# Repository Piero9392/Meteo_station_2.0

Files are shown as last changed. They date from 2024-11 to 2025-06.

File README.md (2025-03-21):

# LoRa-Based Wireless Weather Station 📡📶

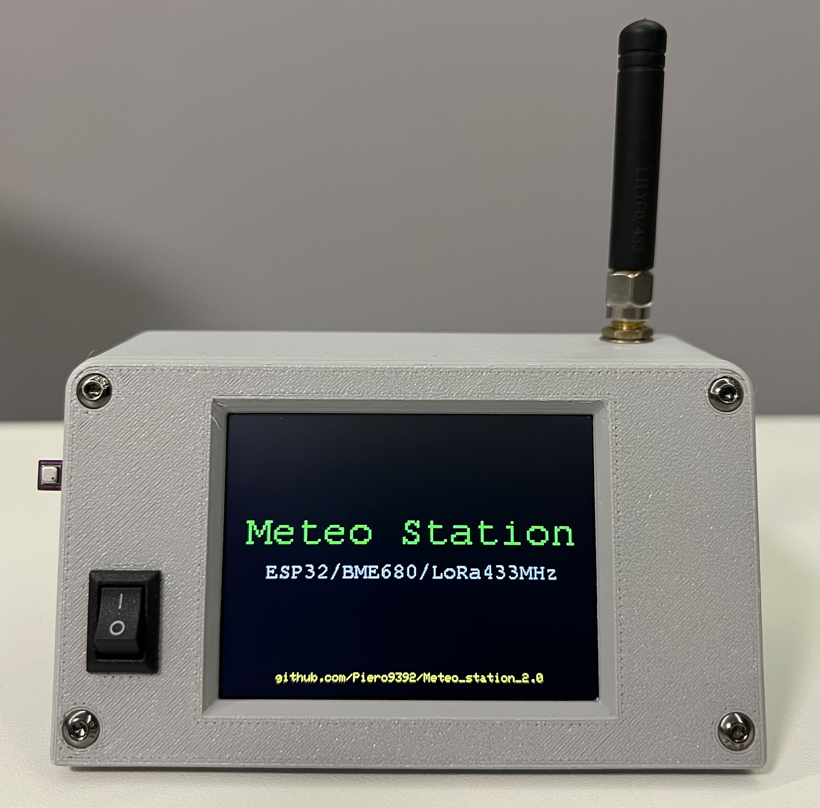
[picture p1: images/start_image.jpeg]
 
 
## Project Overview

This LoRa-based wireless weather station monitors a wide range of environmental parameters, including:
* Temperature 🌡️
* Humidity ☔️
* Pressure ⏱️
* Dew Point 💧
* Gas resistance
* Indoor Air Quality (IAQ) index 💭
* CO₂ 💨
* Volatile Organic Compounds (VOCs) 🗯️
* Altitude ⛰️

The station consists of two LoRa-equipped devices, a Sender and a Receiver, both utilizing the BME680 sensor. The Sender measures environmental parameters and transmits the data over LoRa to the Receiver, which can be positioned several kilometers away. This setup is suitable for applications like monitoring indoor and outdoor environments around your home.

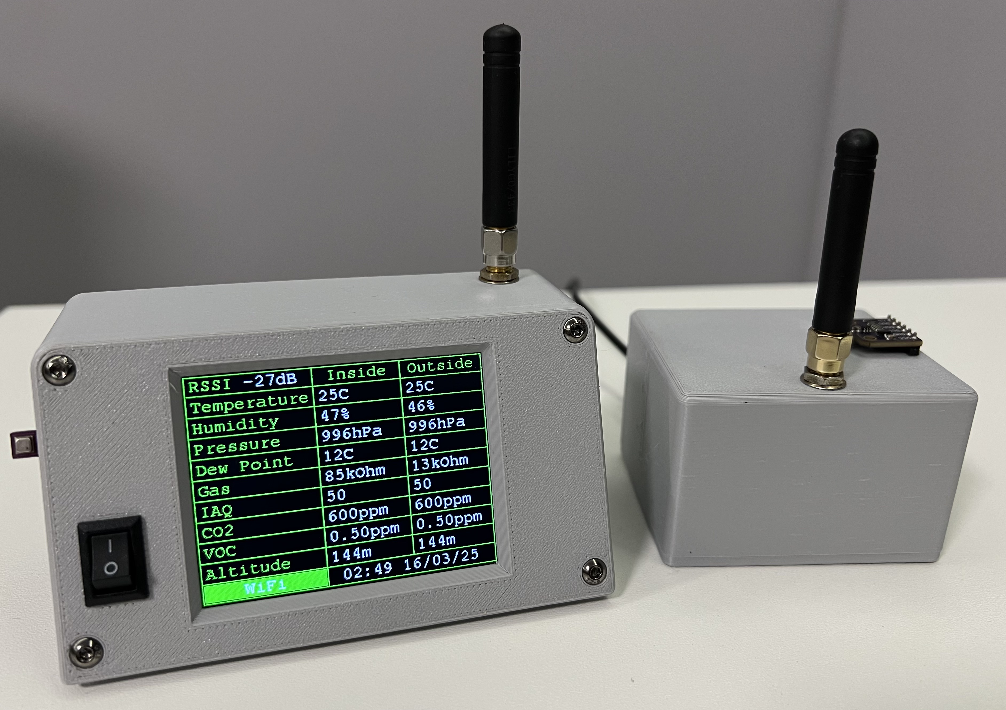
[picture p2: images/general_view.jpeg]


## Data Display and Monitoring

The Receiver provides multiple options for data visualization:
* Onboard Display: View data in real-time on the Receiver’s 2.4-inch TFT screen 🖥️.
* Cloud Integration: Send data via Wi-Fi to Blynk.Cloud or ThingSpeak.com for remote monitoring. You can access real-time and historical data using the Blynk IoT or ThingView applications on iOS/Android or via a web browser 📱🌐.

Additionally, it retrieves the current Time 🕖 and Date 📅 from the NTP server at NTP Pool.

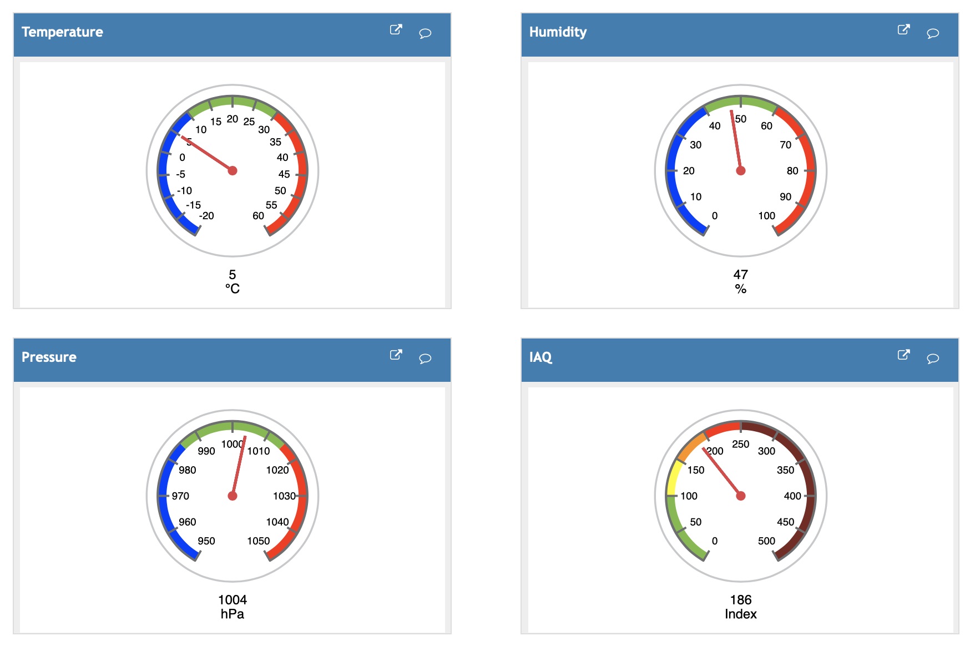
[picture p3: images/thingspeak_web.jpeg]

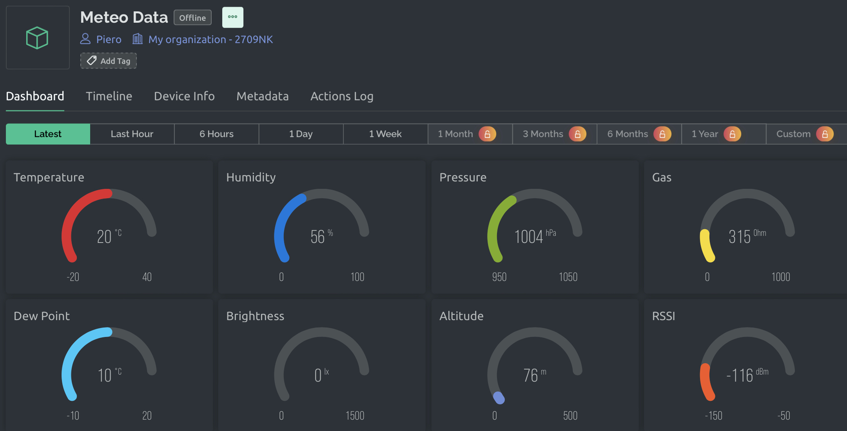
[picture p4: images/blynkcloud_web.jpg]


## Hardware Components

* Sender 📡:
  * 🛠Microcontroller: ESP32 WROOM DA (30 Pins)
  * 🗼Sensor: BME680
  * 📡LoRa: Ra-02 SX1278 (433MHz)
  * DC-DC converter MP1584
  * PCB 60x40mm
  * Capacitor 100mkF

* Receiver 🖥
  * 🛠Microcontroller: ESP32 WROOM DA
  * 🗼Sensor: BME680
  * 📡LoRa: Ra-02 SX1278 (433MHz)
  * 🖥️Display: ILI9341 TFT 2.4-inch screen
  * DC-DC converter MP1584
  * PCB 60x40mm
  * Capacitor 100mkF
  * Switch button
 
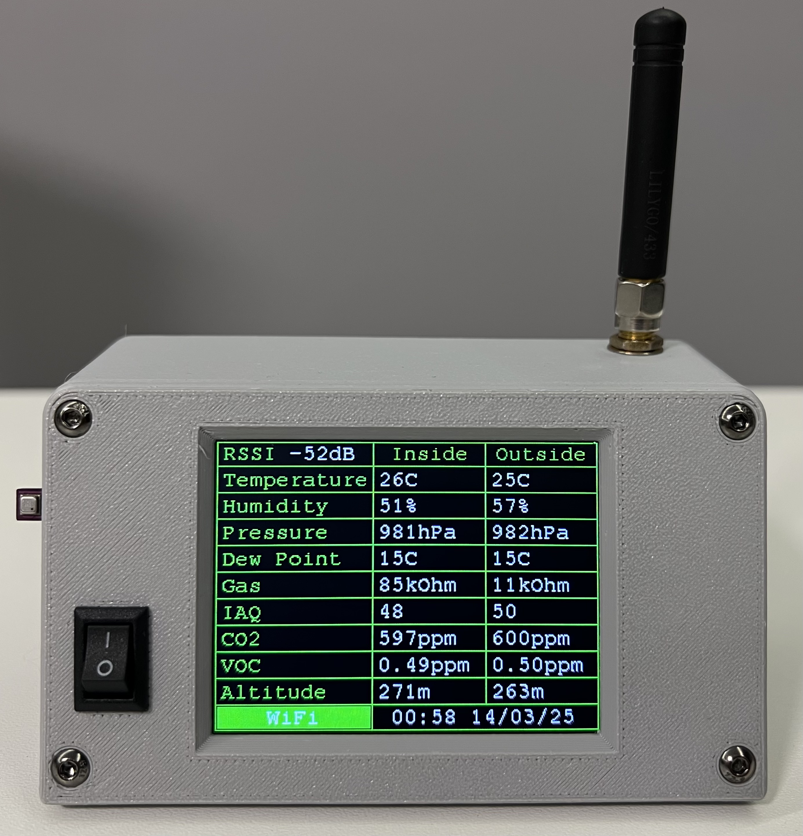
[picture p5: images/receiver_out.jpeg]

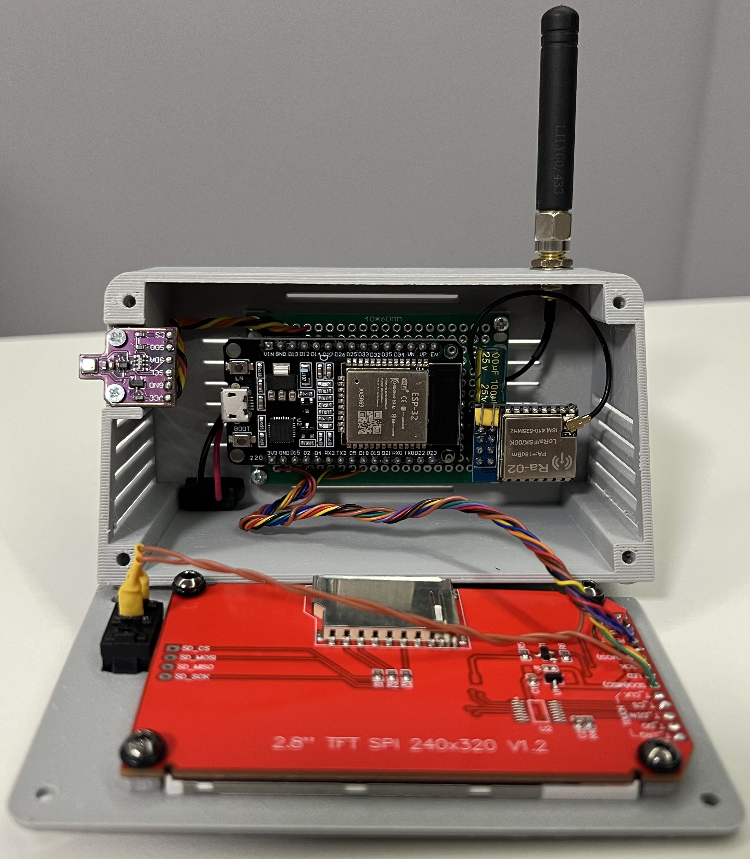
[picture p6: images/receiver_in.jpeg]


## Software
The code for this project is written in C++ using the Arduino IDE.
Key libraries include:
* SPI: For LoRa and TFT-display communication
* BSEC: Provides support for the Bosch BME680 sensor
* LoRa: Enables communication with LoRa (Long Range) transceivers
* WiFi, WiFiClient: For Wi-Fi connectivity on the ESP32
* BlynkSimpleEsp32: For integrating Blynk with ESP32
* AdafruitILI9341, AdafruitGFX: To control ILI9341-based TFT display
* Time: For NTP-based time synchronization

## Wiring and Communication Protocols

The station uses SPI and I2C protocols for communication with the components:
* LoRa Module (SX1278) and TFT Display (ILI9341) communicate with the ESP32 via SPI:
  * MOSI (Master Out Slave In): Data from the ESP32 (master) to the peripheral
  * MISO (Master In Slave Out): Data from peripheral to ESP32
  * SCK (Serial Clock): Synchronizes data transfer
  * CS/SS (Chip Select): Selects the device to communicate with

* BME680 Sensor communicates over I2C:
  * SDA (Data Line)
  * SCL (Clock Line)

### Pin Connections
#### Receiver:

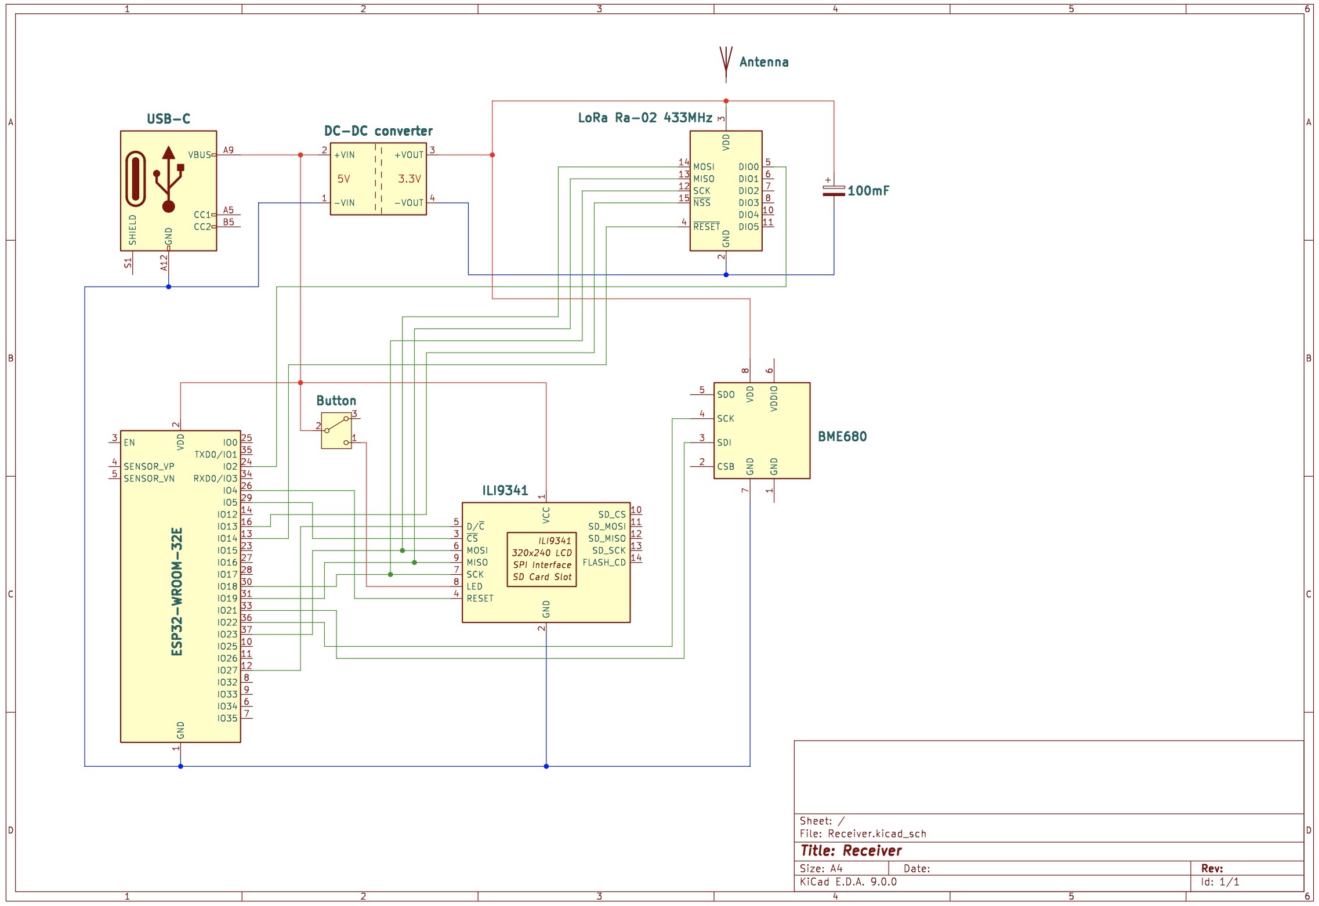
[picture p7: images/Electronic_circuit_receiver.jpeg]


* 📡 LoRa Module (SX1278):
  * MOSI: GPIO 23
  * MISO: GPIO 19
  * SCK: GPIO 18
  * NSS: GPIO 13
  * RESET: GPIO 14
  * DIO0: GPIO 2
  * VCC: +3.3V
  * GND: Ground

* 🖥 TFT Display (ILI9341):
  * MOSI: GPIO 23
  * MISO: GPIO 19
  * SCK: GPIO 18
  * CS: GPIO 5
  * RESET: GPIO 4
  * DC: GPIO 27
  * LED: +5V
  * VCC: +5V
  * GND: Ground

* 🗼BME680 Sensor:
  * SDA: GPIO 21
  * SCL: GPIO 22
  * VCC: +3.3V
  * GND: Ground
 
#### Sender:

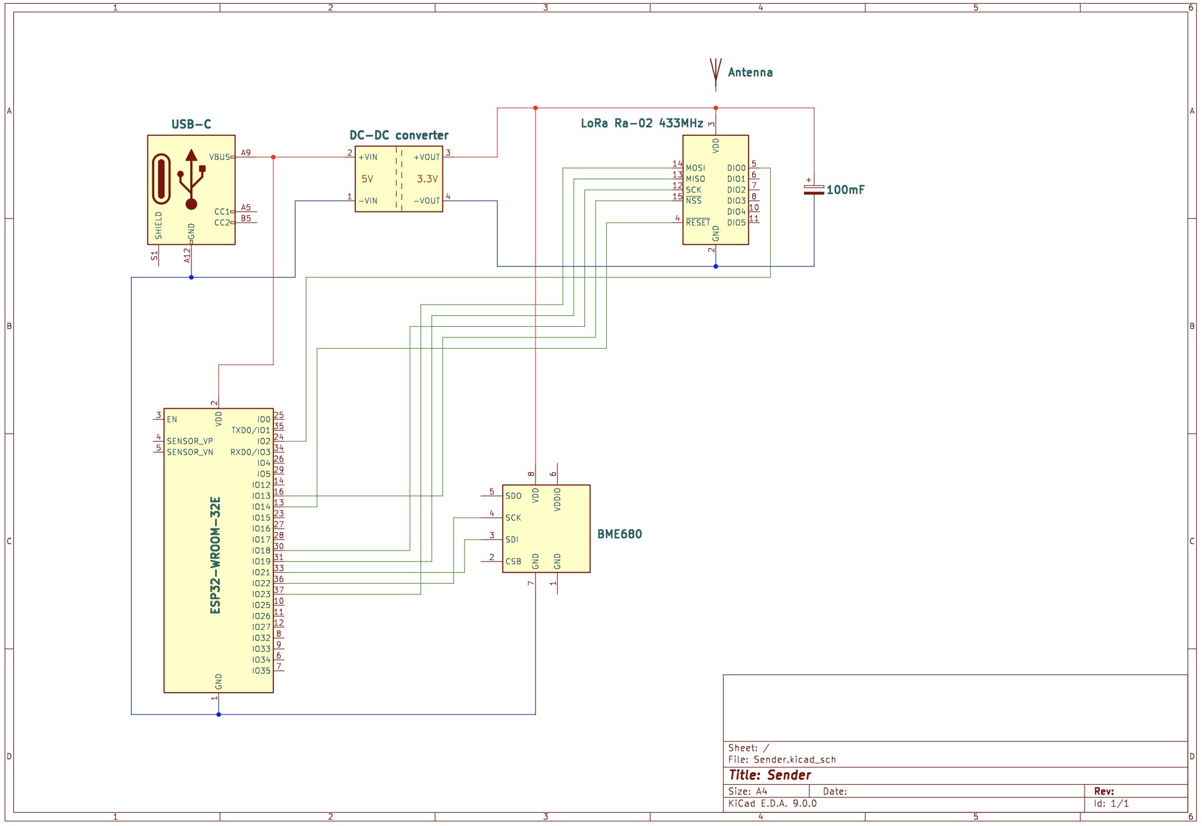
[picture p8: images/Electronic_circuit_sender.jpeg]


* 📡 LoRa Module (SX1278):
  * MOSI: GPIO 23
  * MISO: GPIO 19
  * SCK: GPIO 18
  * NSS: GPIO 13
  * RESET: GPIO 14
  * DIO0: GPIO 2
  * VCC: +3.3V
  * GND: Ground

* 🗼BME680 Sensor:
  * SDA: GPIO 21
  * SCL: GPIO 22
  * VCC: +3.3V
  * GND: Ground

## 3D Printable Case
This project includes **3D files for printing** a custom case and lid for protection and easy mounting.

### Author
Igor Kolesnykov

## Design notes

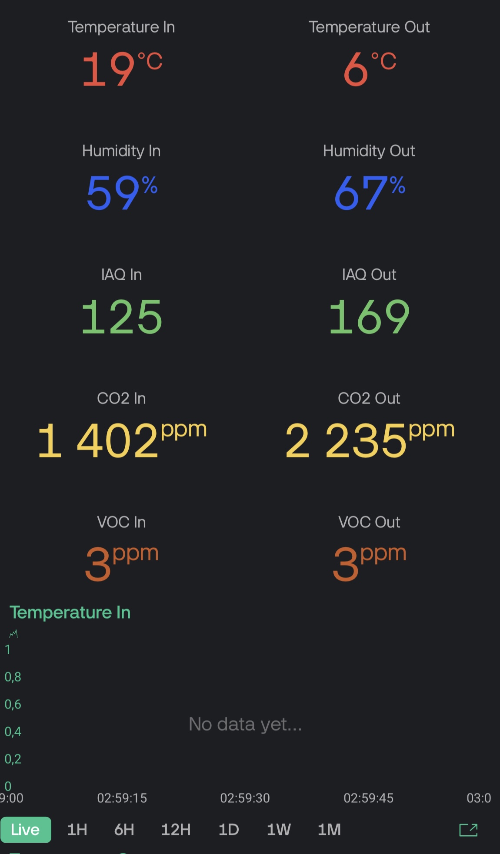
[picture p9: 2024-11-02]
images/blynkcloud_app.jpg

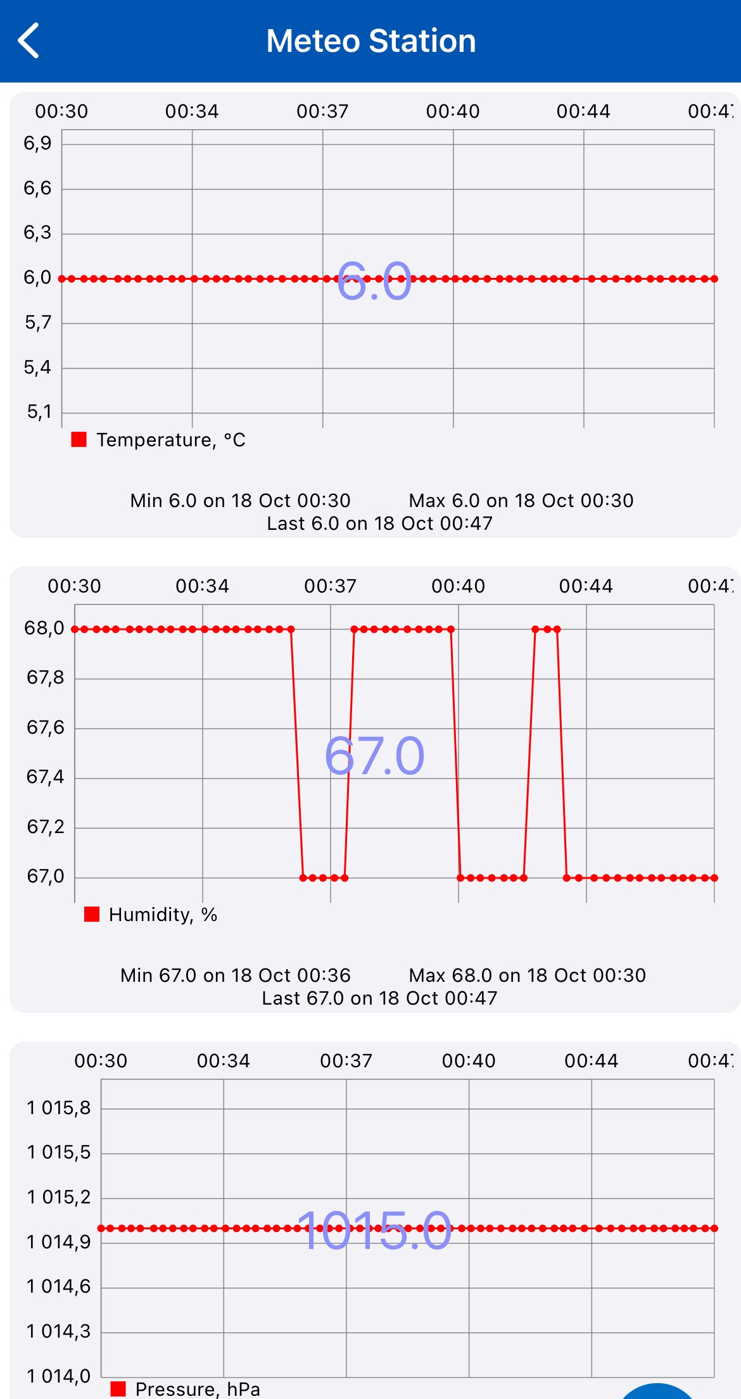
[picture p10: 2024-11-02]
images/thingspeak_app.jpg

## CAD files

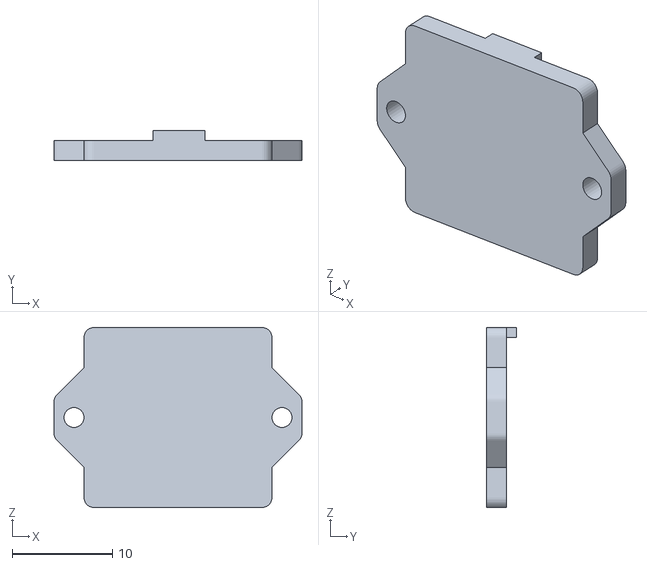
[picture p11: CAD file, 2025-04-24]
3d_models/bme680_lid.stl
24.8 x 3.00 x 18.0

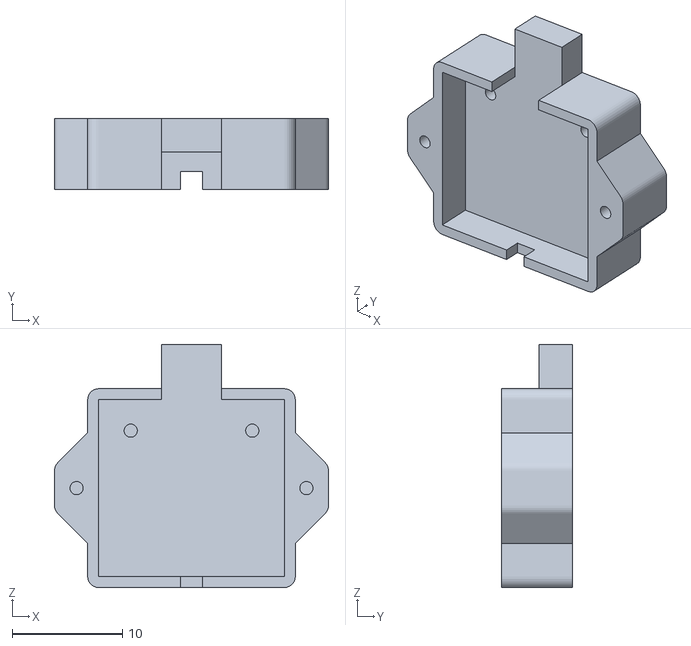
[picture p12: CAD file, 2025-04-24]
3d_models/bme680_box.stl
24.8 x 6.40 x 22.0

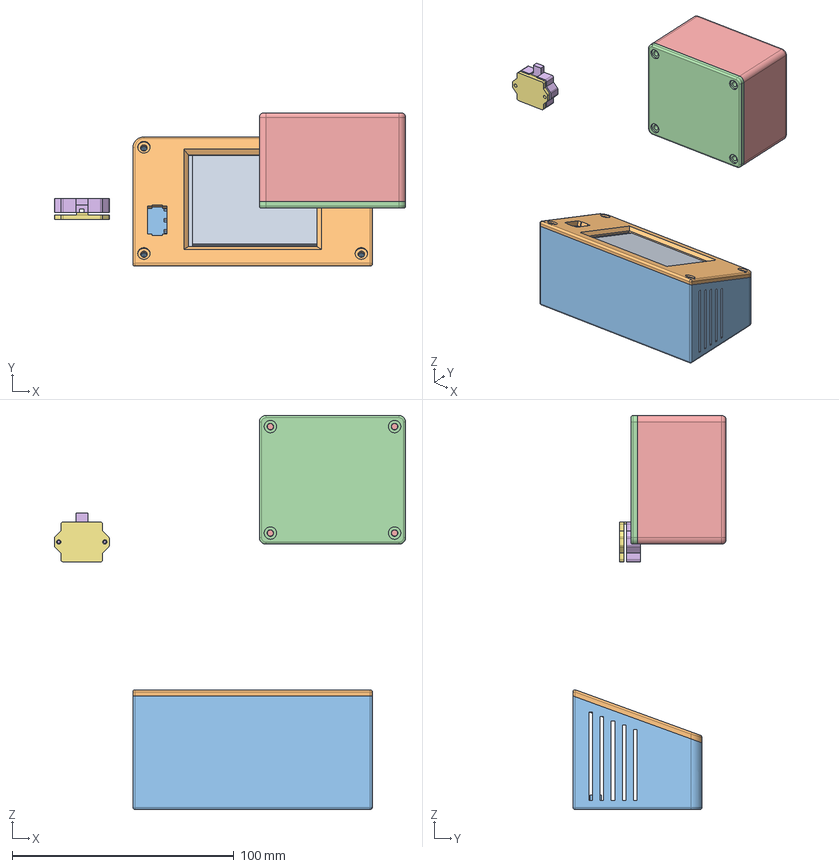
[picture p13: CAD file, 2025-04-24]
3d_models/meteo_station_FreeCAD_model.FCStd
158.4 x 69.1 x 177.6 mm
tft
receiver_lid
receiver_box
sender_lid
sender_box
bme680_box
bme680_lid

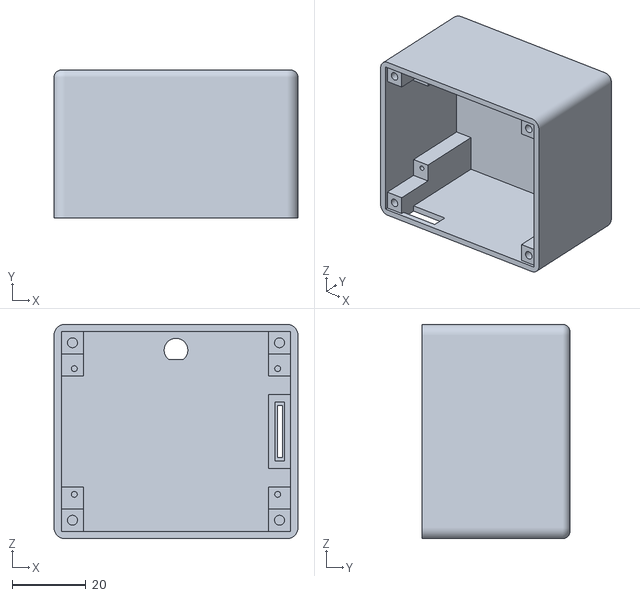
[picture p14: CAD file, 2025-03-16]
3d_models/meteo_station_sender_box.stl
66.0 x 40.0 x 58.0

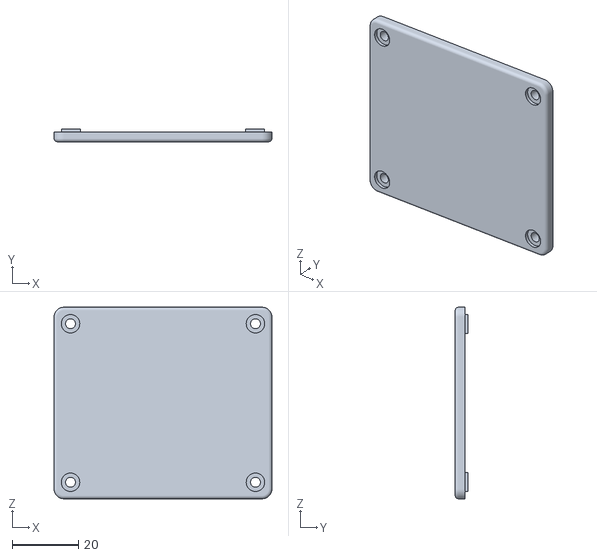
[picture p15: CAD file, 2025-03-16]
3d_models/meteo_station_sender_lid.stl
66.0 x 3.80 x 58.0

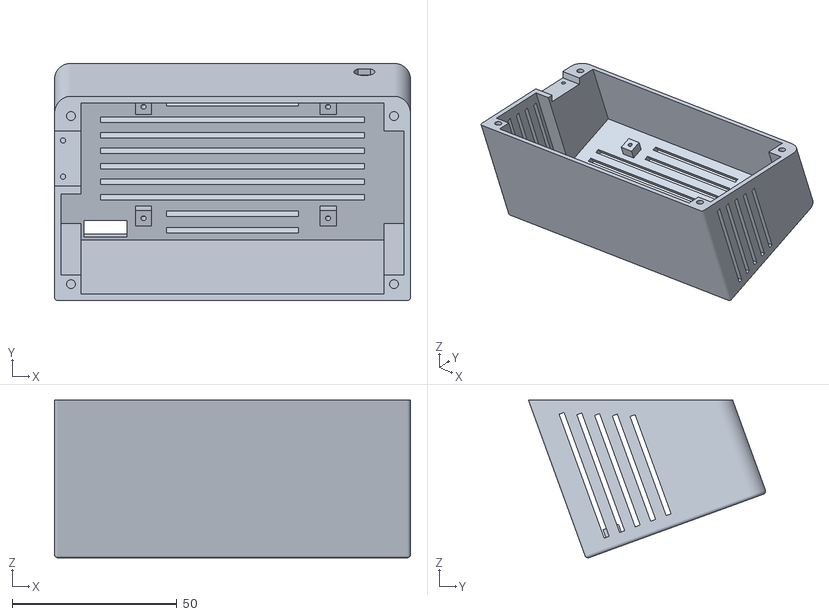
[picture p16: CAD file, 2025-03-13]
3d_models/meteo_station_box_3d_model.stl
108.0 x 72.0 x 47.8

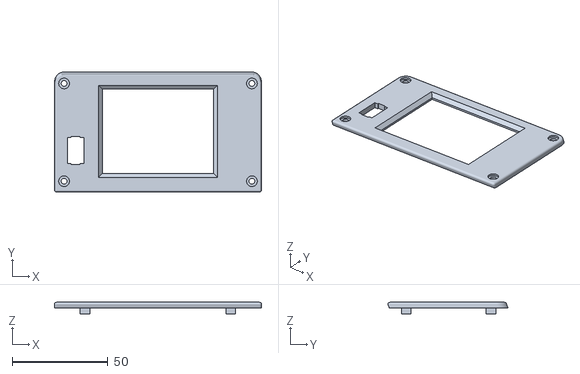
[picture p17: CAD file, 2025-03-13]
3d_models/meteo_station_lid_3d_model.stl
108.0 x 62.7 x 6.00

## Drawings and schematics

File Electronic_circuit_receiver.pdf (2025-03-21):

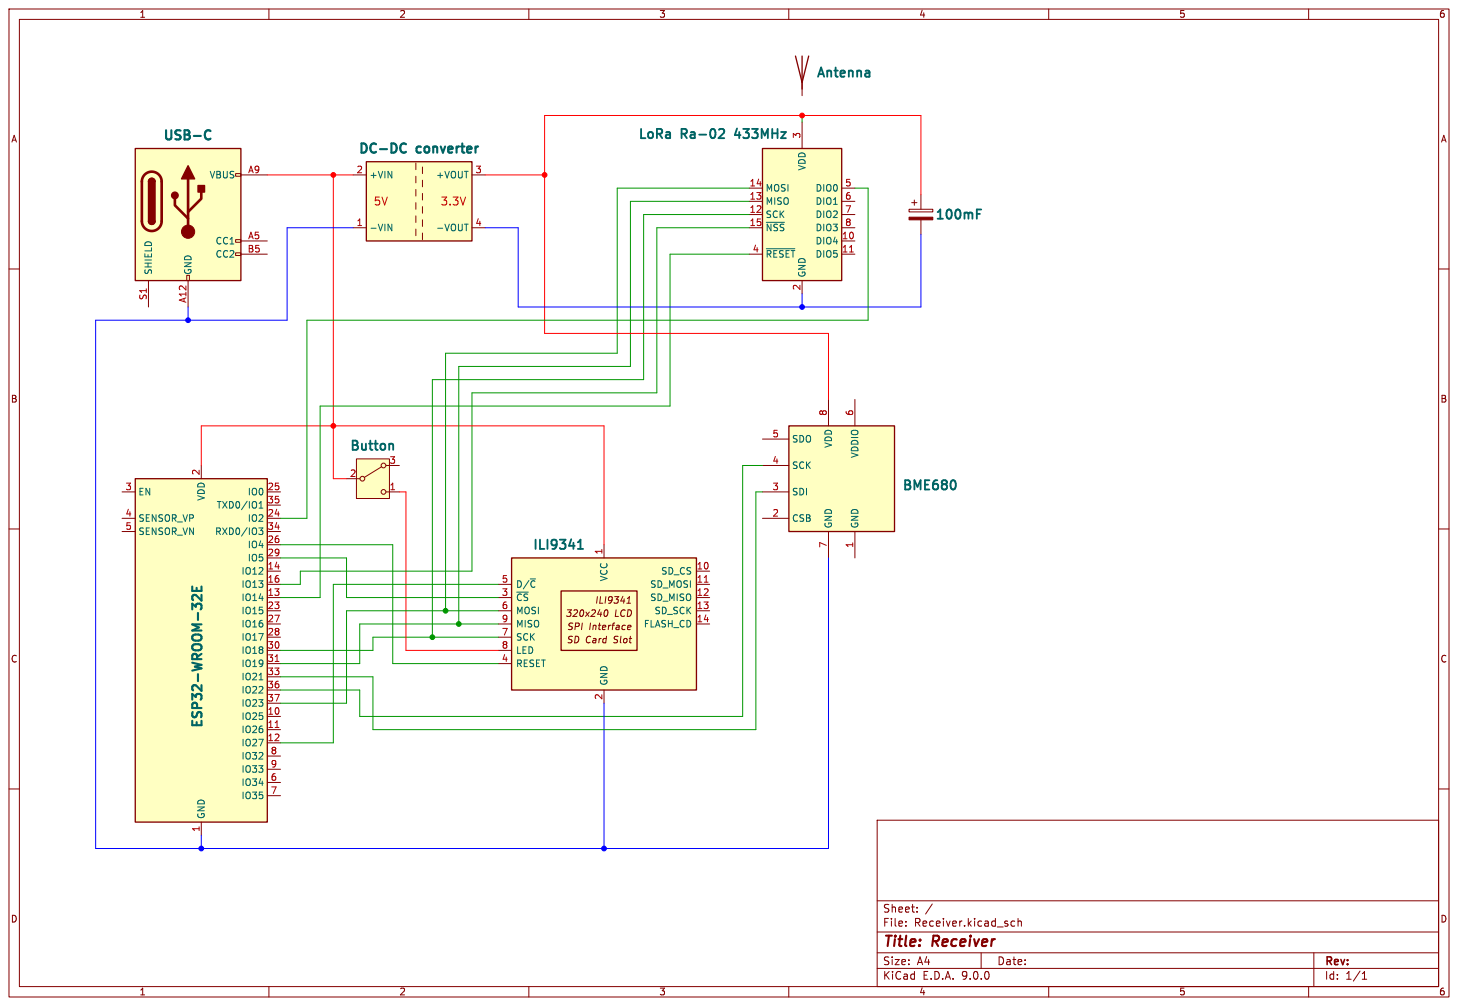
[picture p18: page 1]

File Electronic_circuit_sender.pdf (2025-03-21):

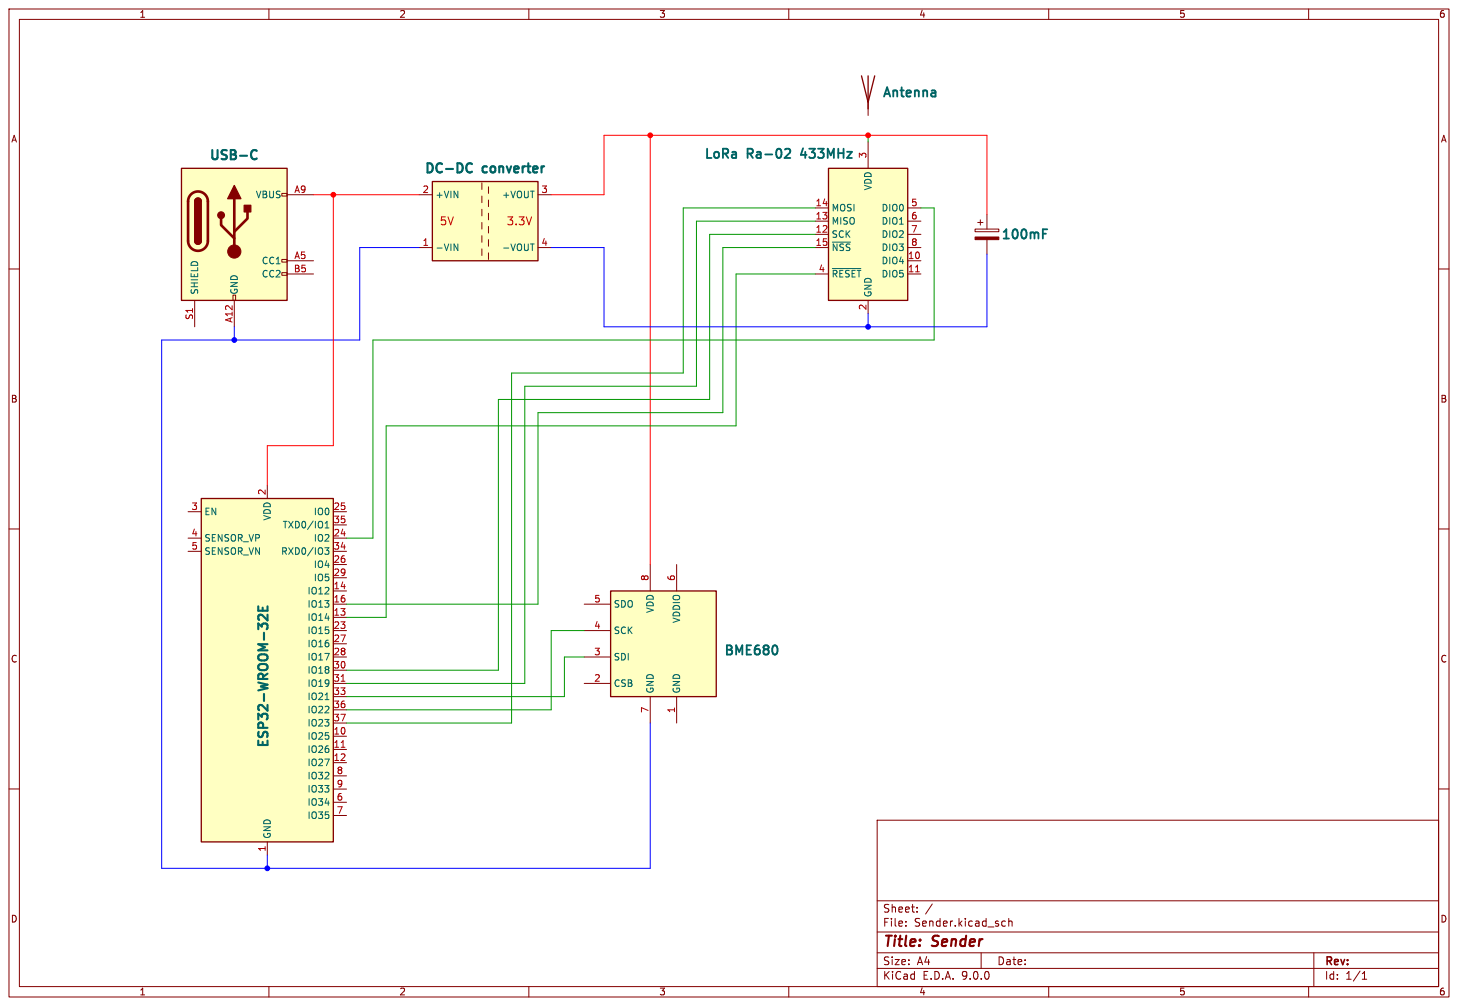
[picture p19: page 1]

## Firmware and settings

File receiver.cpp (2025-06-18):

/*
ILI9341 TFT Display wiring:
MOSI:  GPIO 23
MISO:  GPIO 19
SCK:   GPIO 18
CS:    GPIO 5
RESET: GPIO 4
DC:    GPIO 27
LED:   +5V
VCC:   +5V
GND:   Ground

LoRa Ra-02 wiring:
MOSI:  GPIO 23
MISO:  GPIO 19
SCK:   GPIO 18
NSS:   GPIO 13
RESET: GPIO 14
DIO0:  GPIO 2
VCC:   +3.3V
GND:   Ground

BME680 sensor wiring:
SDA:   GPIO 21
SCL:   GPIO 22
VCC:   +3.3V
GND:   Ground
*/

// Include necessary libraries
#include "bsec.h"
#include <Adafruit_GFX.h>
#include <Adafruit_ILI9341.h>
#include <Fonts/FreeSansBold9pt7b.h>
#include <SPI.h>
#include <LoRa.h>
#include <WiFi.h>
#include <WiFiClient.h>

// Define Blynk template and authentication token
#define BLYNK_TEMPLATE_ID "TMPL40e0QLNIJ"
#define BLYNK_TEMPLATE_NAME "Meteo Station"
#define BLYNK_AUTH_TOKEN "NztOHyQtRNTj9Slwe9euXLEbJFe8ERqi"
#include <BlynkSimpleEsp32.h>

// Pin TFT display configurations
#define TFT_CS 5
#define TFT_RST 4
#define TFT_DC 27

// Pin LoRa configurations
#define SCK 18
#define MISO 19
#define MOSI 23
#define SS 13
#define RST 14
#define DI0 2

// LoRa configuration parameters
#define BAND 433E6
#define SPREADING_FACTOR 12 // Match spreading factor with transmitter
#define SIGNAL_BANDWIDTH 125E3 // Match bandwidth with transmitter
#define CODING_RATE 8 // Match coding rate with transmitter
#define PREAMBLE_LENGTH 8 // Match preamble length with transmitter
#define SYNC_WORD 0x6E // Set custom sync word
#define TX_POWER 20 // Set maximum transmission power in dBm (Ra-02 supports up to 20dBm)

// Pin configurations for BME680
#define SDA 21
#define SCL 22
#define BME680_ADDRESS 0X77

// Initialize objects for TFT display and BME680 sensor
Adafruit_ILI9341 tft = Adafruit_ILI9341(TFT_CS, TFT_DC, TFT_RST);
Bsec iaqSensor;

// Define variables to store sensor data
String device_id;
String temperatureLora;
String humidityLora;
String pressureLora;
String gasLora;
String dewPointLora;
String iaqLora;
String co2Lora;
String vocLora;
String altitudeLora;

// Define variables to store sensor data in integers or floats
int temperatureOut;
int humidityOut;
int pressureOut;
int dewPointOut;
int gasOut;
int iaqOut;
int co2Out;
float vocOut;
int altitudeOut;

// Define variables to store sensor data indices
int temperatureIndex;
int humidityIndex;
int pressureIndex;
int iaqIndex;
int co2Index;
float vocIndex;

// Define colors for TFT display
uint16_t gridColor = ILI9341_GREEN;
uint16_t backgroundColor = ILI9341_BLACK;
uint16_t textColor = ILI9341_WHITE;
uint16_t alertColor = ILI9341_RED;
uint16_t gitTextColor = ILI9341_YELLOW;
uint16_t textColorTemperature;
uint16_t textColorHumidity;
uint16_t textColorPressure;
uint16_t textColorIaq;
uint16_t textColorCo2;
uint16_t textColorVoc;

// Define font for TFT display
const GFXfont* mainFont = &FreeSansBold9pt7b;

// Define WiFi credentials (add your WiFi ssid and password)
const char* ssid1 = "TP-Link_1FAA";
const char* password1 = "10458327";
const char* ssid2 = "UA Guest";
const char* password2 = "ai4democracies";
const char* ssid3 = "";
const char* password3 = "";

// Define Blynk authentication token
char auth[] = BLYNK_AUTH_TOKEN;

// Initialize WiFi client
WiFiClient client;

// Define Thingspeak server and API key
const char* server = "api.thingspeak.com";
String apiKey = "UHID1B0LDCF1AWNU";

// Define NTP server and time settings
const char* ntpServer = "pool.ntp.org";
const long gmtOffset_sec = 7200;
const int daylightOffset_sec = 3600;

// Define timing variables
unsigned long previousMillis = 0;
const unsigned long receiveTimeout = 10000;
unsigned long lastTFTUpdateTime = 0;
const long intervalTimeUpdate = 5000;
const long titleTime = 3000;

bool loraTimeoutDisplayed = false;

// Print grid TFT data
void grid() {
  tft.drawRect(0, 0, 320, 240, gridColor);
  tft.drawLine(130, 0, 130, 240, gridColor);
  tft.drawLine(225, 0, 225, 218, gridColor);
  tft.drawLine(0, 20, 320, 20, gridColor);
  tft.drawLine(0, 42, 320, 42, gridColor);
  tft.drawLine(0, 64, 320, 64, gridColor);
  tft.drawLine(0, 86, 320, 86, gridColor);
  tft.drawLine(0, 108, 320, 108, gridColor);
  tft.drawLine(0, 130, 320, 130, gridColor);
  tft.drawLine(0, 152, 320, 152, gridColor);
  tft.drawLine(0, 174, 320, 174, gridColor);
  tft.drawLine(0, 196, 320, 196, gridColor);
  tft.drawLine(0, 218, 320, 218, gridColor);
}

// Print grid TFT titles
void titleGrid() {
  tft.setFont(mainFont);
  tft.setTextColor(gridColor);
  tft.setTextSize(1);
  tft.setCursor(152, 15);
  tft.println("Inside");
  tft.setCursor(237, 15);
  tft.println("Outside");
  tft.setCursor(8, 36);
  tft.print("Temperature");
  tft.setCursor(8, 58);
  tft.print("Humidity");
  tft.setCursor(8, 80);
  tft.print("Pressure");
  tft.setCursor(8, 102);
  tft.print("Dew Point");
  tft.setCursor(8, 124);
  tft.print("Gas");
  tft.setCursor(8, 146);
  tft.print("IAQ");
  tft.setCursor(8, 168);
  tft.print("CO2");
  tft.setCursor(8, 190);
  tft.print("VOC");
  tft.setCursor(8, 212);
  tft.print("Altitude");
}

// Center the Title text on the TFT
void drawCenteredText(const char *text, int y, uint16_t color, int textSize) {
  int16_t x1, y1;
  uint16_t w, h;
  tft.setTextSize(textSize);
  tft.setTextColor(color);
  tft.getTextBounds(text, 0, y, &x1, &y1, &w, &h);
  tft.setCursor((tft.width() - w) / 2, y);
  tft.print(text);
}

// Display title content
void titleTFT() {
  tft.setRotation(1);
  tft.setFont(mainFont);
  tft.fillScreen(ILI9341_BLACK);
  drawCenteredText("Meteo Station", 110, gridColor, 2);
  drawCenteredText("ESP32 / BME680 / LoRa 433MHz", 140, textColor, 1);
  tft.setFont();
  drawCenteredText("github.com/Piero9392/Meteo_station_2.0", 220, gitTextColor, 1);
  delay(titleTime);
  tft.fillScreen(ILI9341_BLACK);
}

// Helper function to check I2C connection
bool bme680ConnectionCheck() {
  Wire.beginTransmission(BME680_ADDRESS); // Default I2C address for BME680 (0x76 or 0x77)
  if (Wire.endTransmission() != 0) {
    return false;
  }
  return true;
}

// Function to check BME680 wiring
void startBme680(){
  if (!bme680ConnectionCheck()) {
    Serial.println("Failed to initialize BME680");
    tft.setFont(mainFont);
    drawCenteredText("Failed to initialize BME680", 120, alertColor, 1);
    delay(titleTime);
    tft.fillScreen(backgroundColor);
  } else {
    Serial.println("BME680 initializing OK");
  }
}

// Function to initialize BSEC virtual sensors
void bsecVirtualSensor() {
  bsec_virtual_sensor_t sensorList[10] = {
    BSEC_OUTPUT_RAW_TEMPERATURE,
    BSEC_OUTPUT_RAW_PRESSURE,
    BSEC_OUTPUT_RAW_HUMIDITY,
    BSEC_OUTPUT_RAW_GAS,
    BSEC_OUTPUT_IAQ,
    BSEC_OUTPUT_STATIC_IAQ,
    BSEC_OUTPUT_CO2_EQUIVALENT,
    BSEC_OUTPUT_BREATH_VOC_EQUIVALENT,
    BSEC_OUTPUT_SENSOR_HEAT_COMPENSATED_TEMPERATURE,
    BSEC_OUTPUT_SENSOR_HEAT_COMPENSATED_HUMIDITY,
  };
  iaqSensor.updateSubscription(sensorList, 10, BSEC_SAMPLE_RATE_LP);
}

// Function to initialize LoRa communication
void startLora() {
  LoRa.setPins(SS, RST, DI0);
  if (!LoRa.begin(BAND)) {
    Serial.println("Failed to initialize Lora");
    tft.setFont(mainFont);
    drawCenteredText("Failed to initialize Lora", 120, alertColor, 1);
    delay(titleTime);
    tft.fillScreen(backgroundColor);
  }
  else {
  // Adjust LoRa parameters to match transmitter settings
  LoRa.setSpreadingFactor(SPREADING_FACTOR); // Match spreading factor with transmitter
  LoRa.setSignalBandwidth(SIGNAL_BANDWIDTH); // Match bandwidth with transmitter
  LoRa.setCodingRate4(CODING_RATE); // Match coding rate with transmitter
  LoRa.setPreambleLength(PREAMBLE_LENGTH); // Match preamble length with transmitter
  LoRa.setSyncWord(SYNC_WORD); // Set custom sync word
  LoRa.setTxPower(TX_POWER, PA_OUTPUT_PA_BOOST_PIN); // Set maximum transmission power in dBm (Ra-02 supports up to 20dBm). Set transmission power mode

  Serial.println("LoRa 433 MHz Receiver");
  Serial.println("LoRa initializing OK");
  }
}

// Function to start Blynk.Cloud connection
void startWifi() {
  // Array to hold SSIDs
  const char* ssidList[] = {ssid1, ssid2, ssid3};
  // Array to hold passwords
  const char* passwordList[] = {password1, password2, password3};
  int numNetworks = sizeof(ssidList) / sizeof(ssidList[0]);

  // Loop through the networks
  for (int i = 0; i < numNetworks; ++i) {
    WiFi.begin(ssidList[i], passwordList[i]);
    delay(2000); // Allow time to connect

    if (WiFi.status() == WL_CONNECTED) {
      Serial.print("Connected to ");
      Serial.println(ssidList[i]);
      Blynk.begin(auth, ssidList[i], passwordList[i]);
      return; // Exit the loop once connected
    }
  }
  // If no network is available
  Serial.println("No WiFi connection available");
}

// Function to calculate dew point
double dewPointInFunction(double celsius, double humidityIn) {
  double a = 17.271;
  double b = 237.7;
  double temp = (a * celsius) / (b + celsius) + log(humidityIn * 0.01);
  double Td = (b * temp) / (a - temp);
  return Td;
}

// Function to calculate altitude
double altitudeInFunction(double pressureIn) {
  double t = 288.15;       // Standard temperature at sea level (T0)
  double l = 0.0065;       // Temperature lapse rate (L)
  double p = 1013.25;      // Pressure at sea level (P0)
  double r = 8.314462618;  // Universal gas constant (R)
  double g = 9.80665;      // Acceleration due to gravity (G)
  double m = 0.0289644;    // Molar mass of Earth's air (M0)
  double res = pow((pressureIn / p), ((r * l) / (g * m)));
  double Alt = t / l * (1 - res);
  return Alt;
}

// Function to print TFT local time
void printLocalTimeToTft() {
  static String lastTime = "";  // Store last printed time
  struct tm timeinfo;
  getLocalTime(&timeinfo);
  // Format current time as a string
  char timeString[20];
  snprintf(timeString, sizeof(timeString), "%02d:%02d %02d/%02d/%04d", timeinfo.tm_hour, timeinfo.tm_min, timeinfo.tm_mday, timeinfo.tm_mon + 1, timeinfo.tm_year + 1900);
  String currentTime = String(timeString);
  // Only update the display if the time has changed
  if (currentTime != lastTime) {
    tft.fillRect(132, 220, 186, 18, backgroundColor);  // Clear only when needed
    tft.setTextColor(textColor);
    tft.setCursor(153, 234);
    tft.print(currentTime);
    lastTime = currentTime;  // Update last stored time
  }
  Serial.printf("%02d:%02d:%02d %s\n", timeinfo.tm_hour, timeinfo.tm_min, timeinfo.tm_sec, "Time from server");
}

// Function to print TFT WiFi status
void printWifiStatusToTft() {
  long wifiRssi = WiFi.RSSI();  // dBm
  unsigned long currentMillis = millis();
  if (currentMillis - lastTFTUpdateTime >= intervalTimeUpdate) {
    lastTFTUpdateTime = currentMillis;
    if (WiFi.status() == WL_CONNECTED) {
      tft.fillRect(2, 220, 127, 18, gridColor);
      tft.setTextColor(backgroundColor);
      tft.setFont(NULL);
      String wifiRssiMsg = "WiFi RSSI" + String(wifiRssi) + "dBm";
      // Estimate string width: 6 pixels per character
      int textWidth = wifiRssiMsg.length() * 6;
      int rectX = 2;
      int rectY = 220;
      int rectW = 127;
      int rectH = 18;
      int centerX = rectX + (rectW - textWidth) / 2;
      int centerY = rectY + (rectH - 8) / 2;  // 8px is text height in default font
      tft.setCursor(centerX, centerY + 1);  // small Y offset for nicer centering
      tft.print(wifiRssiMsg);
      tft.setFont(mainFont);
      printLocalTimeToTft();
    } else {
      tft.fillRect(2, 220, 127, 18, alertColor);
      tft.setTextColor(textColor);
      tft.setCursor(43, 235);
      tft.print("WiFi");
      tft.fillRect(132, 220, 186, 18, gridColor);
    }
  }
}

// Function to send sensor data to Blynk.Cloud from sensor Inside
void sendSensorInDataToBlynkCloud() {
  int temperatureIn = iaqSensor.temperature;
  int humidityIn = iaqSensor.humidity;
  int iaqIn = iaqSensor.iaq;
  int co2In = iaqSensor.co2Equivalent;
  float vocIn = iaqSensor.breathVocEquivalent;

  Blynk.virtualWrite(V0, temperatureIn);
  Blynk.virtualWrite(V2, humidityIn);
  Blynk.virtualWrite(V4, iaqIn);
  Blynk.virtualWrite(V6, co2In);
  Blynk.virtualWrite(V8, vocIn);
}

// Function to send sensor data to Blynk.Cloud from sensor Outside
void sendSensorOutDataToBlynkCloud() {
  Blynk.virtualWrite(V1, temperatureOut);
  Blynk.virtualWrite(V3, humidityOut);
  Blynk.virtualWrite(V5, iaqOut);
  Blynk.virtualWrite(V7, co2Out);
  Blynk.virtualWrite(V9, vocOut);
}

// Function to send data to Thingspeak
void sendSensorOutDataToThingspeak() {
  if (client.connect(server, 80)) {
    String postStr = apiKey;
    postStr += "&field1=";
    postStr += String(temperatureOut);
    postStr += "&field2=";
    postStr += String(humidityOut);
    postStr += "&field3=";
    postStr += String(pressureOut);
    postStr += "&field4=";
    postStr += String(dewPointOut);
    postStr += "&field5=";
    postStr += String(iaqOut);
    postStr += "&field6=";
    postStr += String(co2Out);
    postStr += "&field7=";
    postStr += String(vocOut);
    postStr += "&field8=";
    postStr += String(altitudeOut);

    client.print("POST /update HTTP/1.1\n");
    client.print("Host: api.thingspeak.com\n");
    client.print("Connection: close\n");
    client.print("X-THINGSPEAKAPIKEY: " + apiKey + "\n");
    client.print("Content-Type: application/x-www-form-urlencoded\n");
    client.print("Content-Length: ");
    client.print(postStr.length());
    client.print("\n\n");
    client.print(postStr);
    delay(300);
  }
  client.stop();
}

void printTemperatureInToTft() {
  int temperatureIn = iaqSensor.temperature;
  tft.fillRect(131, 22, 94, 20, backgroundColor);
  tft.setCursor(135, 36);
  tft.setTextColor(textColorTemperature);
  tft.print(temperatureIn);
  tft.setFont(NULL);
  tft.print(" C");
  tft.setFont(mainFont);
}

void printHumidityInToTft() {
  int humidityIn = iaqSensor.humidity;
  tft.fillRect(131, 44, 94, 20, backgroundColor);
  tft.setCursor(135, 58);
  tft.setTextColor(textColorHumidity);
  tft.print(humidityIn);
  tft.setFont(NULL);
  tft.print(" %");
  tft.setFont(mainFont);
}

void printPressureInToTft() {
  int pressureIn = iaqSensor.pressure / 100;
  tft.fillRect(131, 66, 94, 20, backgroundColor);
  tft.setCursor(135, 80);
  tft.setTextColor(textColorPressure);
  tft.print(pressureIn);
  tft.setFont(NULL);
  tft.print(" hPa");
  tft.setFont(mainFont);
}

void printDewPointInToTft() {
  int temperatureIn = iaqSensor.temperature;
  int humidityIn = iaqSensor.humidity;
  int dewPointIn = dewPointInFunction(temperatureIn, humidityIn);
  tft.fillRect(131, 88, 94, 20, backgroundColor);
  tft.setCursor(135, 102);
  tft.setTextColor(textColor);
  tft.print(dewPointIn);
  tft.setFont(NULL);
  tft.print(" C");
  tft.setFont(mainFont);
}

void printGasInToTft() {
  int gasIn = iaqSensor.gasResistance / 1000;
  tft.fillRect(131, 110, 94, 20, backgroundColor);
  tft.setCursor(135, 124);
  tft.setTextColor(textColor);
  tft.print(gasIn);
  tft.setFont(NULL);
  tft.print(" kOhm");
  tft.setFont(mainFont);
}

void printIaqInToTft() {
  int iaqIn = iaqSensor.iaq;
  tft.fillRect(131, 132, 94, 20, backgroundColor);
  tft.setCursor(135, 146);
  tft.setTextColor(textColorIaq);
  tft.print(iaqIn);
}

void printCo2InToTft() {
  int co2In = iaqSensor.co2Equivalent;
  tft.fillRect(131, 154, 94, 20, backgroundColor);
  tft.setCursor(135, 168);
  tft.setTextColor(textColorCo2);
  tft.print(co2In);
  tft.setFont(NULL);
  tft.print(" ppm");
  tft.setFont(mainFont);
}

void printVocInToTft() {
  float vocIn = iaqSensor.breathVocEquivalent;
  tft.fillRect(131, 176, 94, 20, backgroundColor);
  tft.setCursor(135, 190);
  tft.setTextColor(textColorVoc);
  tft.print(vocIn);
  tft.setFont(NULL);
  tft.print(" ppm");
  tft.setFont(mainFont);
}

void printAltitudeInToTft() {
  int pressureIn = iaqSensor.pressure / 100;
  int altitudeIn = altitudeInFunction(pressureIn);
  tft.fillRect(131, 198, 94, 20, backgroundColor);
  tft.setCursor(135, 212);
  tft.setTextColor(textColor);
  tft.print(altitudeIn);
  tft.setFont(NULL);
  tft.print(" m");
  tft.setFont(mainFont);
}

void printTemperatureOutToTft() {
  tft.fillRect(226, 22, 93, 20, backgroundColor);
  tft.setCursor(230, 36);
  tft.setTextColor(textColorTemperature);
  tft.print(temperatureOut);
  tft.setFont(NULL);
  tft.print(" C");
  tft.setFont(mainFont);
}

void printHumidityOutToTft() {
  tft.fillRect(226, 44, 93, 20, backgroundColor);
  tft.setCursor(230, 58);
  tft.setTextColor(textColorHumidity);
  tft.print(humidityOut);
  tft.setFont(NULL);
  tft.print(" %");
  tft.setFont(mainFont);
}

void printPressureOutToTft() {
  tft.fillRect(226, 66, 93, 20, backgroundColor);
  tft.setCursor(230, 80);
  tft.setTextColor(textColorPressure);
  tft.print(pressureOut);
  tft.setFont(NULL);
  tft.print(" hPa");
  tft.setFont(mainFont);
}

void printDewPointOutToTft() {
  tft.fillRect(226, 88, 93, 20, backgroundColor);
  tft.setCursor(230, 102);
  tft.setTextColor(textColor);
  tft.print(dewPointOut);
  tft.setFont(NULL);
  tft.print(" C");
  tft.setFont(mainFont);
}

void printGasOutToTft() {
  tft.fillRect(226, 110, 93, 20, backgroundColor);
  tft.setCursor(230, 124);
  tft.setTextColor(textColor);
  tft.print(gasOut);
  tft.setFont(NULL);
  tft.print(" kOhm");
  tft.setFont(mainFont);
}

void printIaqOutToTft() {
  tft.fillRect(226, 132, 93, 20, backgroundColor);
  tft.setCursor(230, 146);
  tft.setTextColor(textColorIaq);
  tft.print(iaqOut);
}

void printCo2OutToTft() {
  tft.fillRect(226, 154, 93, 20, backgroundColor);
  tft.setCursor(230, 168);
  tft.setTextColor(textColorCo2);
  tft.print(co2Out);
  tft.setFont(NULL);
  tft.print(" ppm");
  tft.setFont(mainFont);
}

void printVocOutToTft() {
  tft.fillRect(226, 176, 93, 20, backgroundColor);
  tft.setCursor(230, 190);
  tft.setTextColor(textColorVoc);
  tft.print(vocOut);
  tft.setFont(NULL);
  tft.print(" ppm");
  tft.setFont(mainFont);
}

void printAltitudeOutToTft() {
  tft.fillRect(226, 198, 93, 20, backgroundColor);
  tft.setCursor(230, 212);
  tft.setTextColor(textColor);
  tft.print(altitudeOut);
  tft.setFont(NULL);
  tft.print(" m");
  tft.setFont(mainFont);
}

void printRssiSnrLevelToTft() {
  int loraRssi = LoRa.packetRssi();
  int loraSnr = LoRa.packetSnr();
  tft.fillRect(2, 2, 127, 17, gridColor);
  tft.setFont(NULL);  // default font, approx 6x8 px per char
  tft.setTextColor(backgroundColor);
  String loraRssiMsg = "RSSI" + String(loraRssi) + "dBm SNR" + String(loraSnr) + "dB";
  int textWidth = loraRssiMsg.length() * 6;
  int rectX = 2;
  int rectY = 2;
  int rectW = 127;
  int rectH = 17;
  int centerX = rectX + (rectW - textWidth) / 2;
  int centerY = rectY + (rectH - 8) / 2;  // 8px is text height in default font
  tft.setCursor(centerX, centerY + 1);  // small Y offset for nicer centering
  tft.print(loraRssiMsg);
  tft.setFont(mainFont);
}

// Function to print data from sensor Inside to Serial monitor
void printSensorInDataToSerial() {
  int temperatureIn = iaqSensor.temperature;
  int humidityIn = iaqSensor.humidity;
  int pressureIn = iaqSensor.pressure / 100;
  int dewPointIn = dewPointInFunction(temperatureIn, humidityIn);
  int gasIn = iaqSensor.gasResistance / 1000;
  int iaqIn = iaqSensor.iaq;
  int co2In = iaqSensor.co2Equivalent;
  float vocIn = iaqSensor.breathVocEquivalent;
  int altitudeIn = altitudeInFunction(pressureIn);

  Serial.println("Environmental data from Sensor INSIDE:");
  Serial.print("Temperature    | ");
  Serial.print(temperatureIn);
  Serial.println(" \u00B0C");
  Serial.print("Humidity       | ");
  Serial.print(humidityIn);
  Serial.println(" %");
  Serial.print("Pressure       | ");
  Serial.print(pressureIn);
  Serial.println(" hPa");
  Serial.print("Dew Point      | ");
  Serial.print(dewPointIn);
  Serial.println(" \u00B0C");
  Serial.print("Gas resistance | ");
  Serial.print(gasIn);
  Serial.println(" kOhm");
  Serial.print("IAQ            | ");
  Serial.print(iaqIn);
  Serial.println(" Index");
  Serial.print("CO2            | ");
  Serial.print(co2In);
  Serial.println(" ppm");
  Serial.print("VOC            | ");
  Serial.print(vocIn);
  Serial.println(" ppm");
  Serial.print("Altitude       | ");
  Serial.print(altitudeIn);
  Serial.println(" m");
  Serial.println();
}

// Function to print data from sensor Outside to Serial monitor
void printSensorOutDataToSerial() {
  Serial.println("Environmental data from Sensor OUTSIDE:");
  Serial.print("RSSI: ");
  Serial.print(LoRa.packetRssi());
  Serial.println(" dB");
  Serial.print("Temperature    | ");
  Serial.print(temperatureOut);
  Serial.println(" \u00B0C");
  Serial.print("Humidity       | ");
  Serial.print(humidityOut);
  Serial.println(" %");
  Serial.print("Pressure       | ");
  Serial.print(pressureOut);
  Serial.println(" hPa");
  Serial.print("Dew Point      | ");
  Serial.print(dewPointOut);
  Serial.println(" \u00B0C");
  Serial.print("Gas resistance | ");
  Serial.print(gasOut);
  Serial.println(" kOhm");
  Serial.print("IAQ            | ");
  Serial.print(iaqOut);
  Serial.println(" Index");
  Serial.print("CO2            | ");
  Serial.print(co2Out);
  Serial.println(" ppm");
  Serial.print("VOC            | ");
  Serial.print(vocOut);
  Serial.println(" ppm");
  Serial.print("Altitude       | ");
  Serial.print(altitudeOut);
  Serial.println(" m");
  Serial.println();
}
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
void loop() {
  // Run Blynk loop
  Blynk.run();

  // Update WiFi status on TFT display
  printWifiStatusToTft();

  // Read dat Sensor Inside, Sensor Outside and send to Blynk cloud
  sensorInData();
  sensorOutData();
}

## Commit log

2024-11-02 Add 3D models of receiver/transmitter case files
    [receiver_case.FCStd, transmitter_case.FCStd]
2025-03-05 Change the GPIO wire connections and TFT screen rotation
2025-03-05 Change the board (ESP32)
2025-03-13 Add files (FreeCad, *.STL)
    [Meteo_station_FreeCAD_model.FCStd, meteo_station_box_3d_model.stl, meteo_station_lid_3d_model.stl]
2025-03-21 Add sender/receiver electronic circuit PDF
2025-03-21 Add Electronic circuit sender / receiver
2025-03-21 Add ‎Electronic circuit receiver / sender
2025-04-12 Update receiver.cpp
    Add BME680 / Lora failure alert on the screen
    [receiver.cpp]
2025-04-12 Update receiver.cpp
    Change the i2C address from 0x76 to 0x77
2025-04-24 Update the BME680 holder
    [meteo_station_FreeCAD_model.FCStd]
2025-04-24 Add BME680 holder STL files (box and lid)
    [bme680_box.stl, bme680_lid.stl]
2025-06-11 Fix "dB" to "dBm" for RSSI
    [receiver.cpp]
